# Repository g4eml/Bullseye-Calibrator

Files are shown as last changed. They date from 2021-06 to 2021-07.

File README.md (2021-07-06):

# Bullseye-Calibrator
## An Arduino based Calibration tool for the Othernet Bullseye Satellite LNB
### Description
The Othernet Bullseye Satellite LNB is probably the most stable consumer grade Ku Band LNB currently available. Its Temperature Compensated Crystal Oscillator (TCXO) has a specification of ±2ppm and the LNB Local Oscilator is guaranteed by the manufacturer to be within 10Khz of the correct frequency of 9750.0 MHz. The TCXO is adjusted at manufacture to acheive this specification using a proprietary adjustment tool connected to the red connector. All oscillators drift to some extent with time, temperature and mechanical handling, so being able to occasionally re-calibrate them is a usefull feature for the end user.

With the kind support of Othernet and the LNB manufacturer Sy Science and Technology the specification for the adjustment interface has been made available. See the file https://github.com/g4eml/Bullseye-Calibrator/blob/main/Bullseye%20LO%20Re-Alignment%20Procedure.pdf included in this repository. 

This design is for a stand-alone Arduino based calibration tool which allows the LNB TCXO Frequency to be adjusted by the end user. It is also possible to connect this tool to a PC and send adjustment commands. 

Also included in the files is a .STL file for 3D printing a replacement Cap for the LNB. This has a 22mm hole to allow a short length of 22mm copper tube to be pushed in until it touches the Waveguide of the LNB. This then allows the LNB to be connected to a dual band POTY feed for QO-100 use. An alternative version for 23mm tube is also included. 

### Warning!
The Alignment document makes it clear that any attempt to adjust the LNB will invalidate the warranty. If you try to adjust your LNB using this calibrator you are doing so at your own risk.  

### Details
In order to keep construction as simple as possible it was decided to use a readily available and low cost Arduino Nano as the controlling processor. This is programmed with the file https://github.com/g4eml/Bullseye-Calibrator/blob/main/Bullseye_Calibrator.ino using the normal Arduino IDE. Other Arduinos should work equally well. 

The Bullseye LNB is programmed through its Red F Type connector. As detailed in the Alignment Procedure PDF document the interface between the Arduino and the LNB is serial data at 9600 Baud with levels of 0V and +15V. Because the Arduino can only produce data at 5V it is necessary to build a simple level converter circuit using a few low cost components. There are three pushbuttons for control. The interface needs a power supply between 18 and 30 Volts DC. This can be from two 9V batteries or an external power supply. The LNB also needs to be powered through its normal Green F Type connector. 

The schematic for this interface is included in file https://github.com/g4eml/Bullseye-Calibrator/blob/main/Schematic.pdf  None of the parts are particularly critical and may be surface mount or through hole parts. The bill of materials https://github.com/g4eml/Bullseye-Calibrator/blob/main/BOM.pdf has suggested parts with Farnell part numbers.

PCB Files in Eagle format Plus Gerbers are included for both SMT devices and Through Hole devices. 

### Stand-Alone Operation
To adjust the calibration of the LNB using the calibrator you need to do the following...

Set up the LNB as normal using the Green Connector and tune your receiver to a known frequency signal such as one of the QO-100 Beacons, a terrestrial 10GHz beacon or a GPS locked signal source.   

If you are using SDR software that can compensate for LNB errors make sure that this compensation is turned off so that you can see the amount of error that needs correcting. 

Observe the beacon signal, and note how much it needs to be moved in order to indicate the correct frequency. A waterfall display makes this fairly easy.

Allow the LNB temperature to stabilise for about 10 minutes. The LNB will drift a little initially but should then stabilise. 

Connect the calibrator to the LNB Red connector using a short length of 75 ohm cable. (It is not currently known how long this cable can be, if it is too long it may cause problems with the calibration commands.) 

Connect an 18 to 30 V power supply to the calibrator. 

Press the Left or Right buttons to adjust the LNB LO Frequency. This should move in steps of approximately 200Hz. If you need to move a long way you can hold down the button which will then move at 10 steps per second. You should observe the beacon signal moving along the receiver waterfall display.

When the displayed frequency is a close as possible to the correct frequency of the beacon press the SAVE button. This will save the new setting into the LNB memory and will then be used every time the LNB is powered on. 

If you make a mistake press all three buttons at the same time. This will restore the factory calibration value. 

### PC Operation
It is also possible to connect the Calibrator to a PC through the Arduino USB port. This allows the calibration commands to be sent from the PC Keyboard. 
Use a Terminal program on the PC and set the communications to 9600 Baud, 8 Bits, No Parity, 1 Stop Bit. 
Commands are single upper case characters as listed in the PDF document.

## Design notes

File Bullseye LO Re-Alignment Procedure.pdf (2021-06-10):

# Ultra High Stability LNB

# LO Re-Alignment

08th JUN 2020

Slide 2

DISCLAIMER

Updating the LNB via the program port will invalidate any warranty and is done so at the risk of the end user.

There are certain command strings that will alter the internal algorithms of the compensation so please do not attempt to send random or arbitrary commands to the LNB. It is therefore highly recommended to buffer the serial data from any PC application with a secondary MCU to reduce the risk of issuing the wrong command directly to the LNB. This can easily be achieved with a simple MCU relaying and limiting the commands to the ones listed in the following pages or by having external switches controlling the MCU and relaying only the listed commands.

During the development of the Bullseye LNB we used the best components we could source and keep costs low and no matter what references you select they will all drift with time so the function to re-align the LO was built into the original design to enable digital control of the internal LO. The following document will outline the required steps to allow the Internal LO of the Bullseye LNB to be realigned and moved on the fly. LO is either a 9.75 or 10.6GHz LO and the internal circuits allow a certain amount of adjustment. A typical LNB can be altered approximately 230kHz @ 9.75GHz with a resolution of around 200Hz. Serial commands can move the LO in 1, 4 or 10X resolution steps and can be non-volatile or stored in the internal flash enabling the LO setting to be recalled on power cycling. The original factory calibration can be also be recalled back in to the USER memory. Note the LO is Low side so incrementing the LO results in a decrement of the L-band.

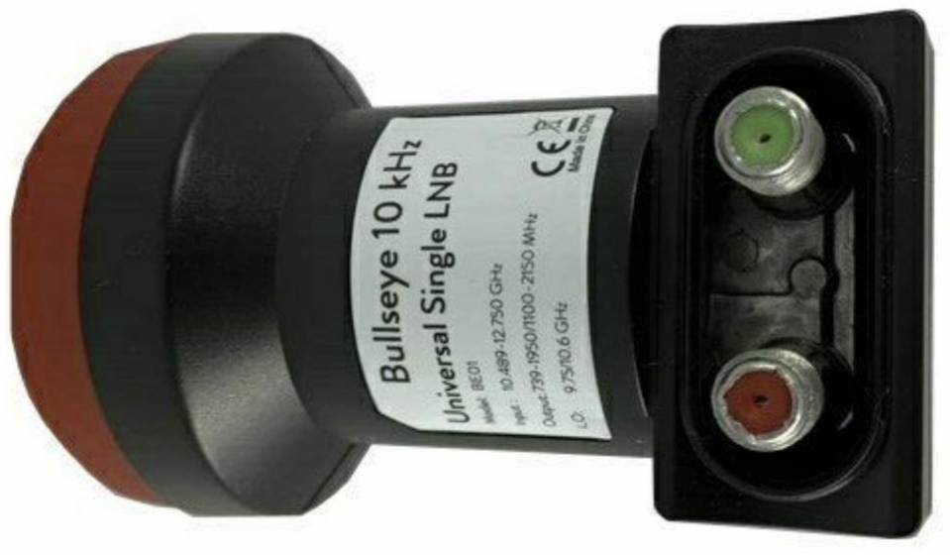
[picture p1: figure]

RF OUT FROM SAT & DC/22k

REF/PROGRAM PORT

COMMANDS for SY BIAS TEE/PROGRAMMER

LNB Controller Serial Protocol = 9600 Baud, 1 Start bit, 1 stop bit & No Parity& no handshaking.

Tone Box Commands
BIAS CONTROLLER ONLY

T = Tone On
t = Tone Off
V = 13V
v = 17V

Frequency Adjust Commands
LNB WILL ACCEPT

Q = Decrement x 1
A = Decrement x 4
Z = Decrement x 10

W = Increment x 1
S = Increment x 4
X = Increment x 10

D = Min Frequency Offset
E = Max Frequency Offset
C = Mid Frequency Offset

Store Commands
LNB WILL ACCEPT

U = Store User Frequency in Memory
M = Recall User Frequency from Memory
P = Restore Factory Frequency to User Memory

Reset Commands:

R = Reboot Bias Tee

## NOTE: If you are constructing your own Programmer then go to next page)

COMMANDS for LNB ONLY

LNB Controller Serial Protocol = 9600 Baud, 1 Start bit, 1 stop bit & No Parity, no handshaking. Series 1k to LNB Program port & 15V/0V signaling

Frequency Adjust Commands
LNB WILL ACCEPT

Q = Decrement x 1
A = Decrement x 4
Z = Decrement x 10

W = Increment x 1
S = Increment x 4
X = Increment x 10

D = Min Frequency Offset
E = Max Frequency Offset
C = Mid Frequency Offset

Store Commands
LNB WILL ACCEPT

U = Store User Frequency in Memory
M = Recall User Frequency from Memory
P = Restore Factory Frequency to User Memory

IF connecting direct to the Program Port on the LNB a 1k 5% or better resistor MUST be fitted in series with the serial driver

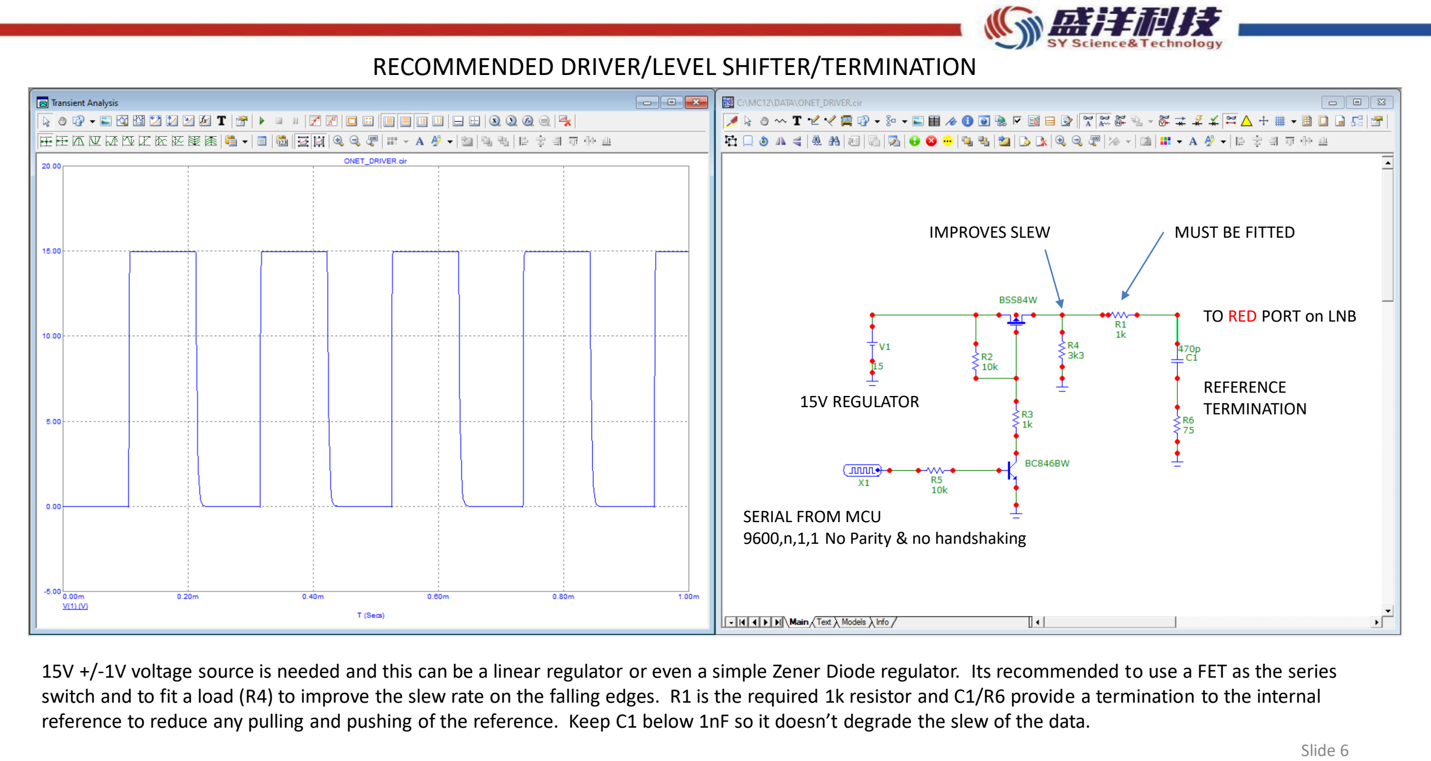
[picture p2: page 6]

RECOMMENDED DRIVER/LEVEL SHIFTER/TERMINATION

15V +/-1V voltage source is needed and this can be a linear regulator or even a simple Zener Diode regulator. Its recommended to use a FET as the series switch and to fit a load (R4) to improve the slew rate on the falling edges. R1 is the required 1k resistor and C1/R6 provide a termination to the internal reference to reduce any pulling and pushing of the reference. Keep C1 below 1nF so it doesn’t degrade the slew of the data.

SERIAL FROM MCU
9600,n,1,1 No Parity & no handshaking

15V REGULATOR

REFERENCE
TERMINATION
IMPROVES SLEW | MUST BE FITTED

TO RED PORT on LNB

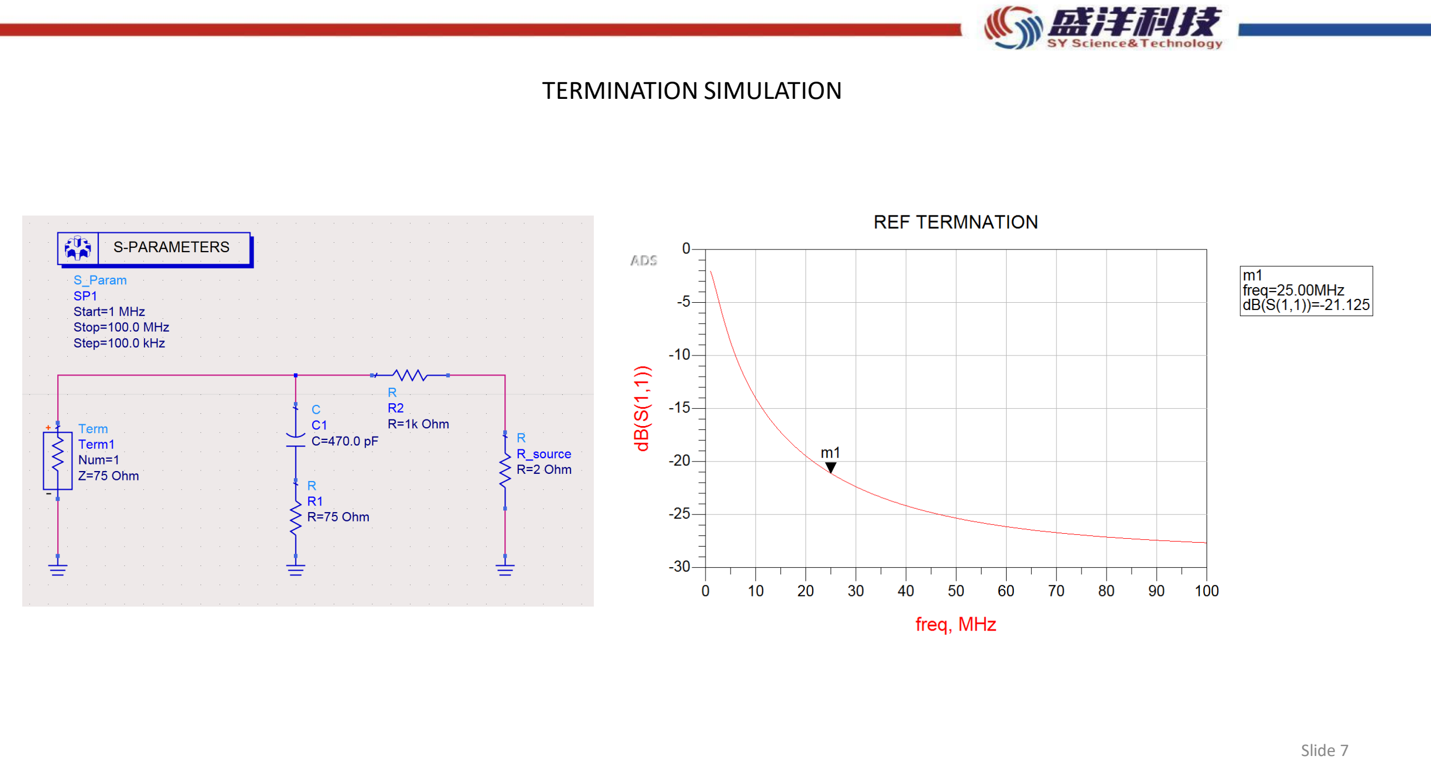
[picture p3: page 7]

TERMINATION SIMULATION

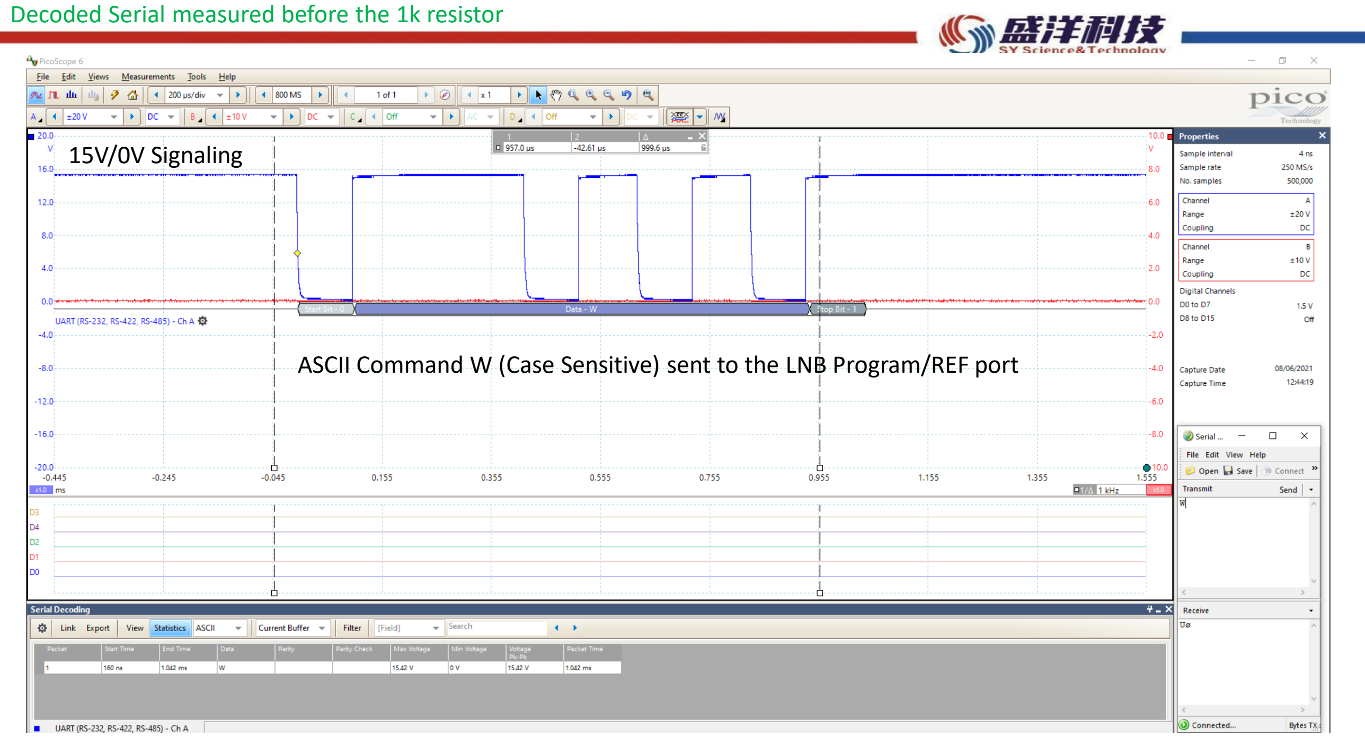
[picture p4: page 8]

ASCII Command W (Case Sensitive) sent to the LNB Program/REF port

15V/0V Signaling

Decoded Serial measured before the 1k resistor

The LNB will accept the case sensitive ASCII commands presented however the level needs to be 15V/0V with clean edges as the routines in the LNB are bit banged, excessive slew may cause issues with reception. Internally a complex network couples off (approx. 25 – 30dB) the reference so there is no real requirement for termination at 25MHz but is recommended for best performance, an external 1k 5% resistor MUST be added before any reference diplexer to setup the levels internal to the LNB. The program port is rugged and direct connection to 21V will not damage the programmer port. The 15V supply and external 1k resistor is used to set the exact threshold levels for the LNB MCU is just another safety mechanism.

During manufacture we align the LO with a GPS locked Ku CW source and once tuned to the exact frequency (within the resolution of the LO stepping) the values are copied to 2 independent sectors in memory. One sector is the User Cal and the other is the Factory Cal. Commands can be issued to move the LO and are non volatile until the command U is issued, where the current LO Offset values and calculated constants are written to the USER flash sector. The factory CAL sector remains unaltered and on reboot the User CAL will be loaded at all times. In the event that the original factory value is ever needed then issuing command P will copy the factory CAL sector back into the User Flash sector and the original factory calibration is recovered.

There are obviously commands to overwrite and setup the user calibration and issuing these will invalidate any warranty to spec. There is no reason to ever change these constants as the internal algorithms will be impacted corrupting stability and temperature dependance and once changed cannot be recovered, so please don’t fire random commands at the LNB in an event to play around with them you are likely only going to brick the device. We record all values referenced to serial numbers so if units are returned we will know they have been overwritten and the LNB will be recycled and not returned so be warned….

Have Fun!

SY team

## END OF PRESENTATION

## THANKS!

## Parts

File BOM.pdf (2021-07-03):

BOM for Bullseye Calibrator

Reference | Description | SMT Part No. | Farnell | Leaded Part No. | Farnell
TR1 | P-Channel FET | BSS84P | 1056526 | TP2104N3-G | 2775067
TR2 | NPN Transistor | BC846B | 1798074 | BC548B | 2985391
IC1 | 15V 100mA Regulator | LM3480 IM3-15 | 3007553 | UA78L15ACLP | 2781824
D1 | 150 mA diode | 1N4148WS | 2675148 | 1N4148TR | 1469384
R1,R3 | 10K Resistor 125mW | MCWR08X1002FTL | 2447553 | MF12 10K | 9342419
R2,R5 | 1K Resistor 125mW | MCWR08X1001FTL | 2447587 | MF12 1K | 9342400
R4 | 3K3 Resistor 125mW | MCWR08X3301FTL | 2447651 | MF12 3K3 | 9343040
R6 | 75 Ohm Resistor 125mW | MCWR08X75R0FTL | 2447721 | MF12 75R | 9343555
C1,C2 | 100nF 30V | MC0805B104K500CT | 1759265 | MCFYU6104Z6 | 9411887
C3 | 470pF 30V | MC0805B471K500CT | 1759216 | MCBU5471K5 | 9411771
J1 | 2.1mm Power Socket | | | FC681478 | 2450496
J2 | F Type Socket | | | 5-1634540-1 | 1248987
J3 | 2 Pin Header | | | TSW-102-07-G-S | 2505044
S1,S3,S3 6mm Tactile Switch | B3F-1022 | 1829495
M1 | Arduino Nano Module | (Buy it from Ebay. Much Cheaper!) | A000005 | 1848691

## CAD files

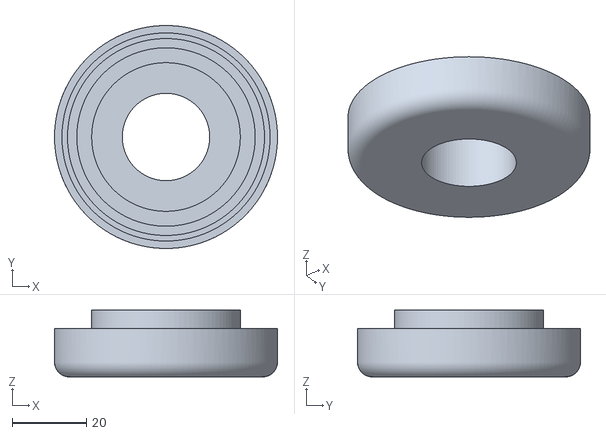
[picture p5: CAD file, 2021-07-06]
23mm Poty Adaptor.stl
60.0 x 60.0 x 18.0

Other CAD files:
22mm POTY Adaptor.stl

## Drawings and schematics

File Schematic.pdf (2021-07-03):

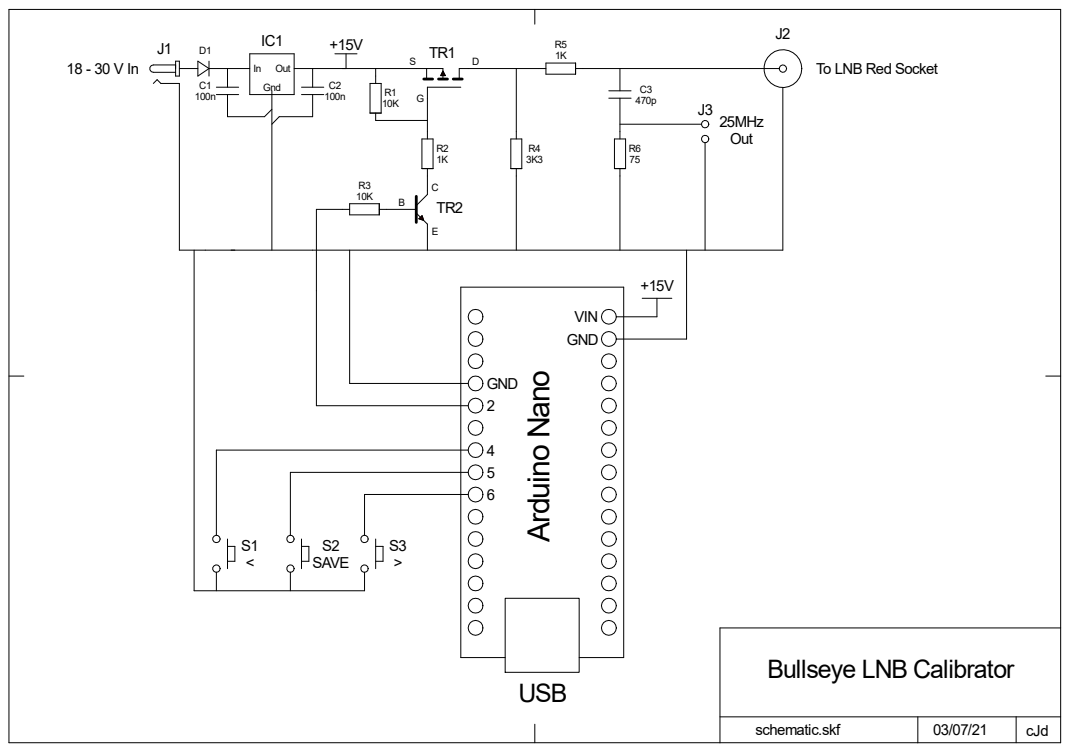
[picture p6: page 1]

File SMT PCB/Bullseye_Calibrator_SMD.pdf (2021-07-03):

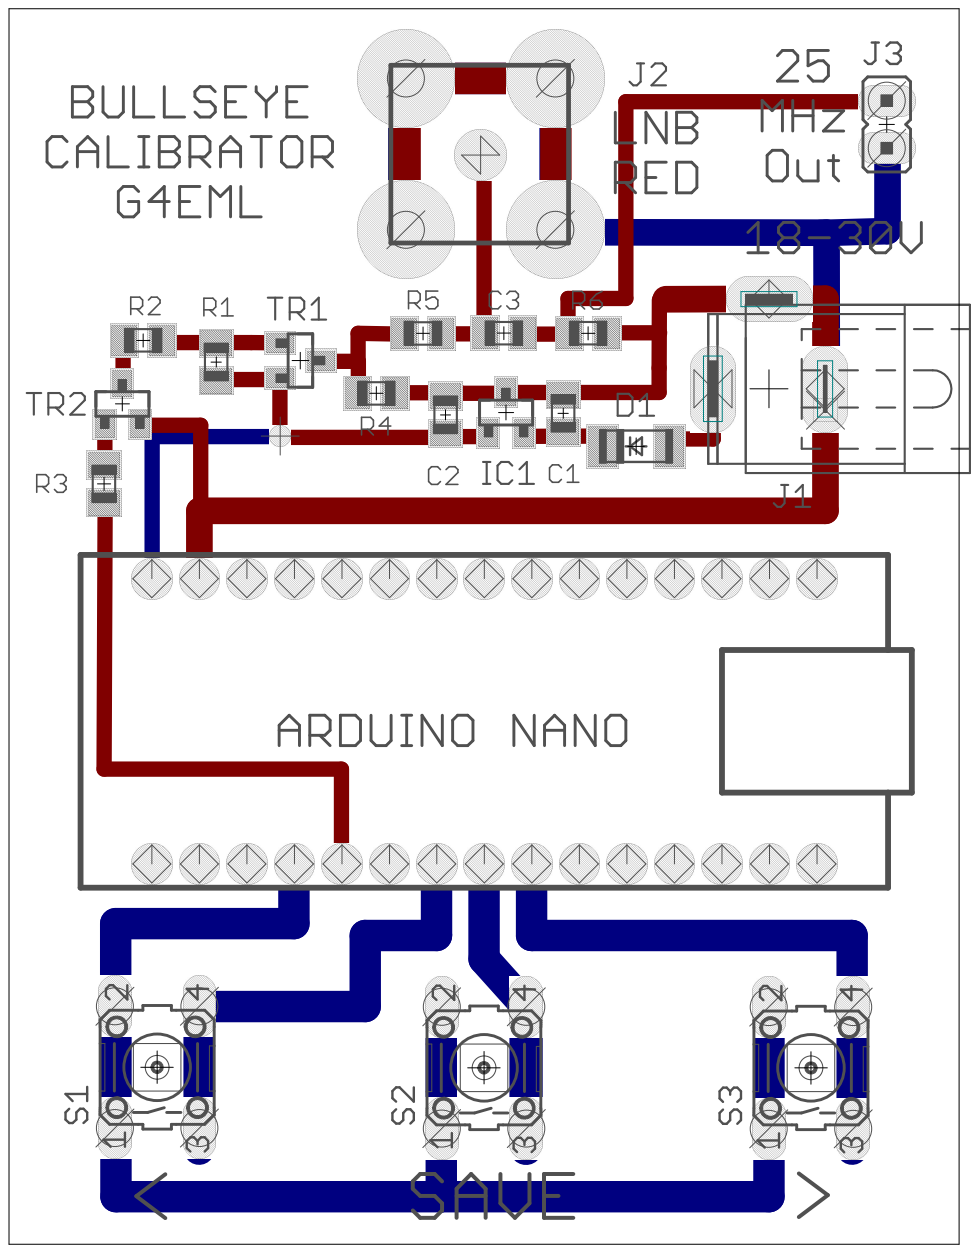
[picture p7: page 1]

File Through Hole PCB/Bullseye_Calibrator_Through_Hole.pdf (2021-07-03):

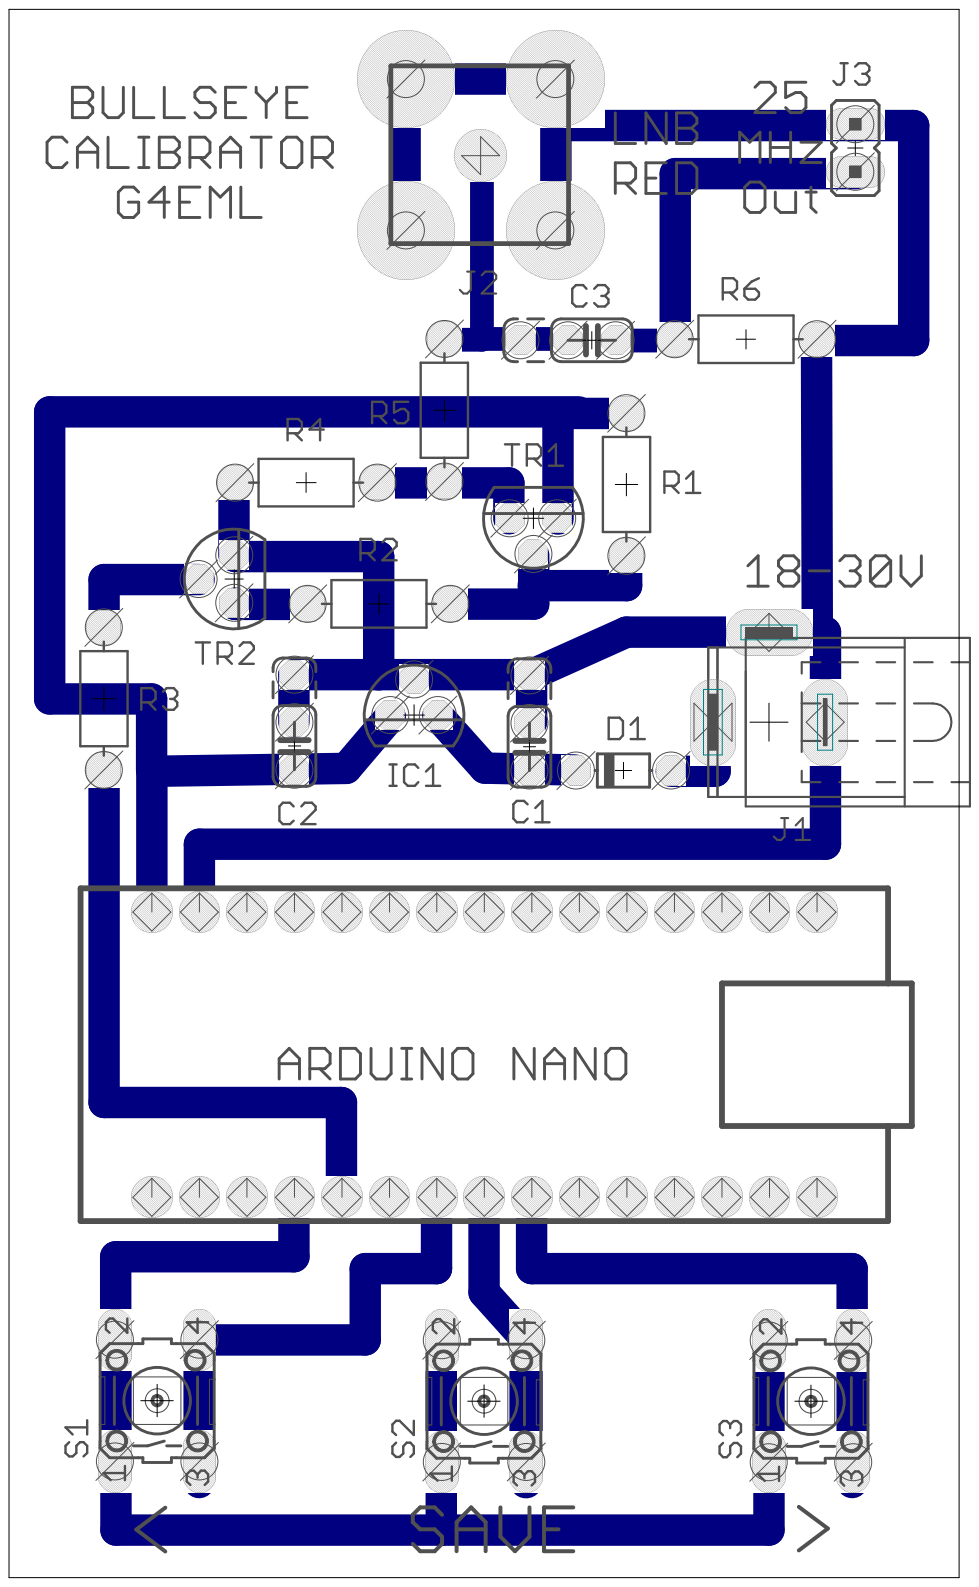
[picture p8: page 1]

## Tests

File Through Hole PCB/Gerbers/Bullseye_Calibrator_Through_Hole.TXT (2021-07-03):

%
M48
M72
T01C0.0315
T02C0.0320
T03C0.0360
T04C0.0394
T05C0.0400
T06C0.0433
T07C0.0906
%
T01
X3109Y8105
X4109Y8105
X5109Y8105
X6109Y8105
X7109Y8105
X8109Y8105
X9109Y8105
X10109Y8105
X11109Y8105
X12109Y8105
X13109Y8105
X14109Y8105
X15109Y8105
X16109Y8105
X17109Y8105
X17109Y14105
X16109Y14105
X15109Y14105
X14109Y14105
X13109Y14105
X12109Y14105
X11109Y14105
X10109Y14105
X9109Y14105
X8109Y14105
X7109Y14105
X6109Y14105
X5109Y14105
X4109Y14105
X3109Y14105
X16100Y19990
X17281Y18100
T02
X14037Y17083
X12037Y17083
X11057Y17086
X11057Y18086
X11057Y19086
X11139Y21641
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

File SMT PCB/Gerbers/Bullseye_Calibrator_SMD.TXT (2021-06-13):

%
M48
M72
T01C0.0197
T02C0.0236
T03C0.0315
T04C0.0360
T05C0.0394
T06C0.0400
T07C0.0433
T08C0.0906
%
T01
X5809Y17107
T02
X17290Y17650
T03
X17109Y8105
X16109Y8105
X15109Y8105
X14109Y8105
X13109Y8105
X12109Y8105
X11109Y8105
X10109Y8105
X9109Y8105
X8109Y8105
X7109Y8105
X6109Y8105
X5109Y8105
X4109Y8105
X3109Y8105
X3109Y14105
X4109Y14105
X5109Y14105
X6109Y14105
X7109Y14105
X8109Y14105
X9109Y14105
X10109Y14105
X11109Y14105
X12109Y14105
X13109Y14105
X14109Y14105
X15109Y14105
X16109Y14105
X17109Y14105
X17281Y18100
X16100Y19990
T04
X18578Y23163
X18578Y24163
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

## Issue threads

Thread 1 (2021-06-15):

Debounce bug for SAVE

localhosthack0r, 2021-06-15:
Hi,
I don't know if this has practical relevance, but when reading through your code, I saw this bug:
https://github.com/g4eml/Bullseye-Calibrator/blob/f40e6ebdf924d636e243ee5be80b13e0547c1966/Bullseye_Calibrator.ino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

if (debounce=20)
is an assignment and will always return true.

g4eml, 2021-06-15:
Thanks, typo Corrected.

Closed 2021-06-15.

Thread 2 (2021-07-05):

Generate 23mm POTY Adaptor variant

m1dst, 2021-07-05:
Would it be possible to generate and upload an adapter for a 23mm tube?  DJ7GP uses a 23mm aluminum tube and your adapter is designed for the normal 22mm copper heating pipe.  It would be really great if you could help.

m1dst, 2021-07-06:
I managed to modify your existing STL so not required by me anymore.

g4eml, 2021-07-06:
I have added a 23mm version for anyone that needs it.

Closed 2021-07-06.

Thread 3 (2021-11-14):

Ready Built Calibrator

xtranerd, 2021-11-14:
Hi I read that you may still have some Ready Built Calibrators for sale. Are there any left ?

thanks,

James G1PVZ

g4eml, 2021-11-14:
Sorry,  all gone.

Colin G4EML

On 14 Nov 2021, at 18:30, xtranerd ***@***.***> wrote:

Hi I read that you may still have some Ready Built Calibrators for sale. Are there any left ?

thanks,

James G1PVZ

—
You are receiving this because you are subscribed to this thread.
Reply to this email directly, view it on GitHub, or unsubscribe.
Triage notifications on the go with GitHub Mobile for iOS or Android.

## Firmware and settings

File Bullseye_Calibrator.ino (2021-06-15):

// Calibrator for Othernet Bullseye LNB
// Written by Colin Durbridge G4EML for an Arduino Nano. However it should work on any Arduino. 
// Based on data supplied by SY Science and Technology and Othernet. Thanks to Jon and Syed.
//
// This program allows the LO of the Bullseye LNB to be adjusted in steps of approximately 200Hz.
// Three pushbuttons, connected between Arduino pins and ground, are used. Plus, Minus and Save.
// Pressing the Plus or Minus buttons moves the LO by one step in either direction. Holding the button down results in 10 steps per second. 
// Pressing the Save button stores this new calibration as the user setting which will then be used every time the LNB is powered up. 
// Pressing all three buttons together will restore the factory calibration. 
//
// Single character commands can also be sent from a PC connected to the Arduino USB Serial port. Settings are 9600 8,N,1 
// Valid commands are as follows. 
// 
// Q = Decrement by 1    W = Increment by 1    D = Min Frequency
// A = Decrement by 4    S = Increment by 4    E = Max Frequency
// Z = Decrement by 10   X = Increment by 10   C = Mid Frequency
//
// U = Store User Frequency in Memory
// M = Recall User Frequency from Memory
// P = Restore Factory Frequency from Memory
//
// The LNB must be powered up as normal through the Green Port. The serial output of the Arduino on pin 2 must be level shifted with an external circuit to 0-15V (±1V)and connected via a 1K resistor to the Red Port. 
//


#include <SoftwareSerial.h>

SoftwareSerial LNBSerial(3, 2); // RX on Arduino pin 3 (Not Used) , TX on Arduino Pin 2 (Level shifted and connected to Red Port of LNB)

char valid[]="ACDEMPQSUWXZ";    //Valid commands for Bullseye LNB. WARNING! Do not try other commands, they may corrupt the settings)
char inChar[]="#";
int debounce;
int repeatDelay;
int ledDelay;
int buttons;
enum {NONE,PLUS,MINUS,PLUSMINUS,SAVE,PLUSSAVE,MINUSSAVE,ALL};
unsigned long lastTick;
char factoryReset;

#define PLUSBUT 4                  //pin for Plus Button (connect a push botton between this Arduino pin and Ground)
#define SAVEBUT 5                  //pin for Save Button (connect a push botton between this Arduino pin and Ground)
#define MINUSBUT 6                 //pin for Minus Button (connect a push botton between this Arduino pin and Ground)

void setup() 
{
  // initialize Hardware serial port to PC
  Serial.begin(9600);
  //initialise Software Serial port to LNB
  LNBSerial.begin(9600);

  pinMode(PLUSBUT,INPUT_PULLUP);
  pinMode(SAVEBUT,INPUT_PULLUP);
  pinMode(MINUSBUT,INPUT_PULLUP);
  pinMode(LED_BUILTIN,OUTPUT);

  debounce=0;
  repeatDelay=0;
  ledDelay=0;
  lastTick=millis();
  factoryReset=0;
  
}

void loop() 
{
  
// read from PC if available and send to LNB

  if (Serial.available())            //Have we received a character from the PC?
  {
    inChar[0] = Serial.read();       //Get the character from the PC
    if(strpbrk(inChar,valid))        //Test if that Character is a valid command
    {
      digitalWrite(LED_BUILTIN,1);
      ledDelay=10;
      repeatDelay=10;
      LNBSerial.write(inChar[0]);    //Send the character to the LNB
    }

  }

//Read Buttons and combine into one variable

  buttons = NONE;
  if(digitalRead(PLUSBUT)==LOW) buttons = buttons + PLUS;
  if(digitalRead(MINUSBUT)==LOW) buttons = buttons + MINUS;
  if(digitalRead(SAVEBUT)==LOW) buttons = buttons + SAVE;

  switch (buttons)
   {
    case NONE:
      repeatDelay=100;
      break;

    case PLUS:
      if((debounce==0) | (repeatDelay==0))
        {
           LNBSerial.write("W");
           digitalWrite(LED_BUILTIN,1);
           ledDelay=10;
           if(repeatDelay==0) repeatDelay=10;
        }
      if(debounce<20) debounce=20;
      break;
    
    case MINUS:
      if((debounce==0) | (repeatDelay==0))
        {
           LNBSerial.write("Q");
           digitalWrite(LED_BUILTIN,1);
           ledDelay=10;
           if(repeatDelay==0) repeatDelay=10;
        }
      if(debounce<20) debounce=20;
      break;
   
    case SAVE:
      if(debounce==0) 
      {
        LNBSerial.write("U");
        digitalWrite(LED_BUILTIN,1);
        ledDelay=10;
      }
      if (debounce<20) debounce=20; 
      break;

      case ALL:
      factoryReset=1;
      digitalWrite(LED_BUILTIN,1);
      ledDelay=10;
      debounce=100;    
      break;  
   }


//Send factory reset if requested

   if((factoryReset==1) & (debounce==0))
   {
     LNBSerial.write("P");
     factoryReset=0;
     for(int c=0;c<6;c++)
     {
      digitalWrite(LED_BUILTIN,1);
      delay(100);
      digitalWrite(LED_BUILTIN,0);
      delay(100);
     }
   }


//Do this every 10 ms to implement delays.

  if(millis()>=lastTick+10)
    {
      lastTick=millis();
      if(repeatDelay>0)
        {
          repeatDelay=repeatDelay-1;
        }
      if(debounce>0)
        {
          debounce=debounce-1;
        }
      if(ledDelay>0)
        {
          ledDelay=ledDelay-1;
        }
      else
        {
          digitalWrite(LED_BUILTIN,0);
        }
    }



}
